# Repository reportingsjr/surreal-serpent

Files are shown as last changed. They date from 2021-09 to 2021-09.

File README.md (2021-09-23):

This light ring is intended to go on the intake of a fume extractor I am designing.

The assembly can be done by JLC excluding the Molex Picoblade connector on the back.

The input is a 12V PWM signal. At 100% duty cycle the current draw is approximately 450mA, divided evenly(ish) across ten strings of LEDs.

This project is only half organized, because I spent more time than I wanted on the design and assembly steps and don't feel like spending more energy organizing a hobby project. :)

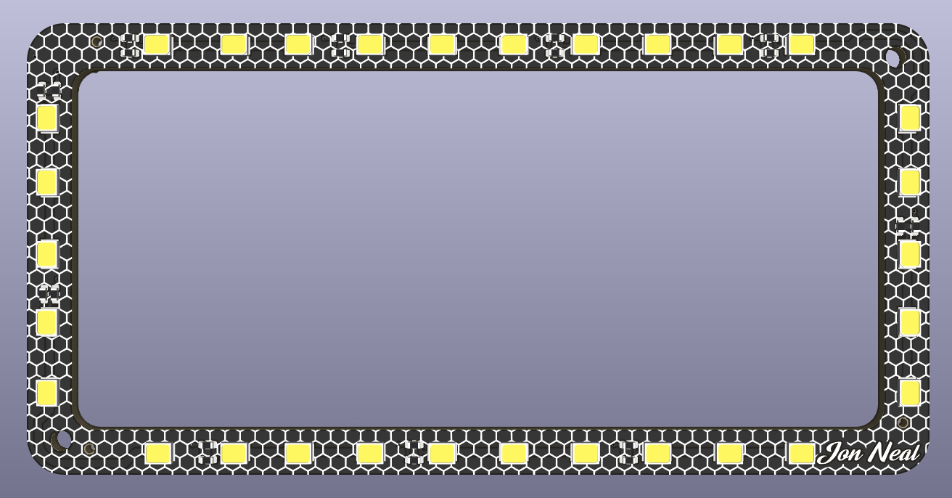
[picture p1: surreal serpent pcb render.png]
PCB Render


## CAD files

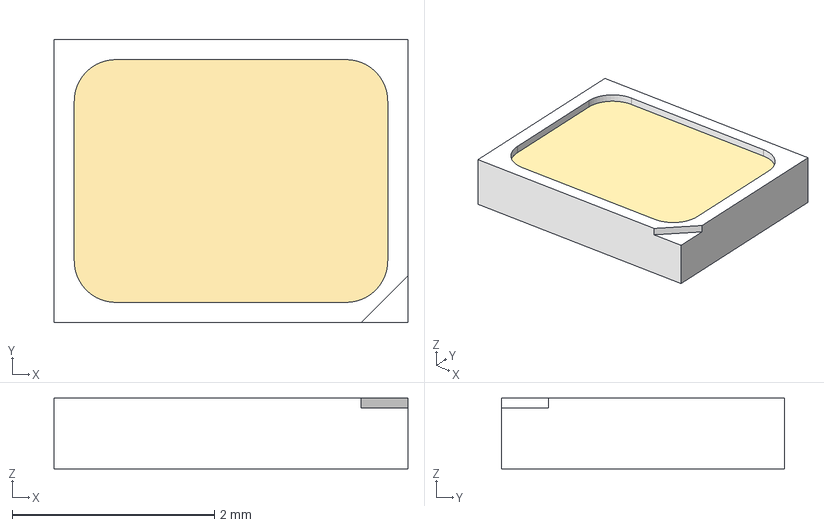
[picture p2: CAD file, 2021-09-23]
C210316.step
3.50 x 2.80 x 0.7 mm

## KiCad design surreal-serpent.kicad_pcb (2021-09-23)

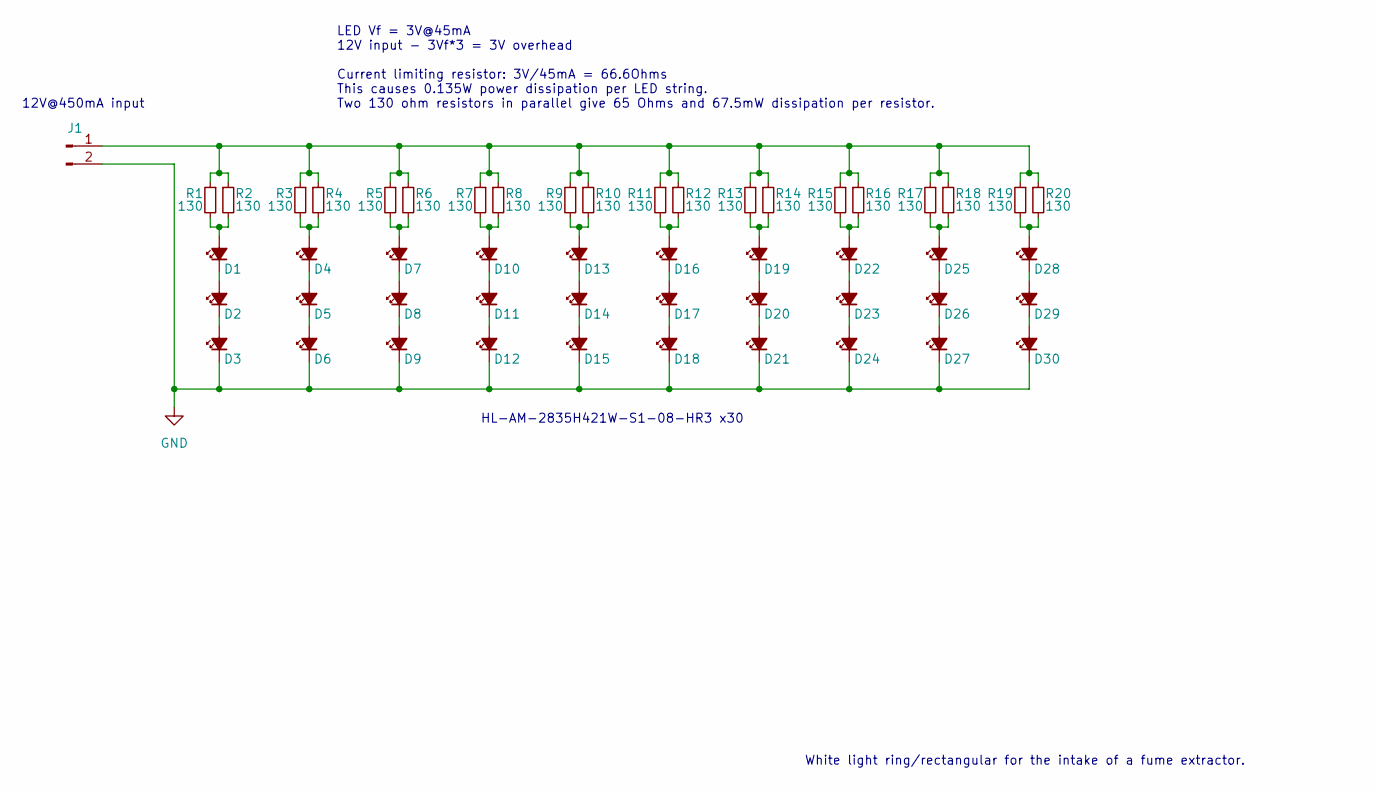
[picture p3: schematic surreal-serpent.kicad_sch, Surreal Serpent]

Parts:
D1, D2, D3, D4, D5, D6, D7, D8, D9, D10, D11, D12, D13, D14, D15, D16, D17, D18, D19, D20, D21, D22, D23, D24, D25, D26, D27, D28, D29, D30: HL-AM-2835H421W-S1-08-HR3; C210316; LCSC C210316
J1: Conn_01x02_Male; Molex_PicoBlade_53261-0271_1x02-1MP_P1.25mm_Horizontal; part number 0532610271
R1, R2, R3, R4, R5, R6, R7, R8, R9, R10, R11, R12, R13, R14, R15, R16, R17, R18, R19, R20: 130; R_0603_1608Metric; LCSC C22796

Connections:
GND: D3.1 (K), D6.1 (K), D9.1 (K), D12.1 (K), D15.1 (K), D18.1 (K), D21.1 (K), D24.1 (K), D27.1 (K), D30.1 (K), J1.2
unnamed: D1.1 (K), D2.2 (A)
unnamed: D1.2 (A), R1.2, R2.2
unnamed: D2.1 (K), D3.2 (A)
unnamed: D4.1 (K), D5.2 (A)
unnamed: D4.2 (A), R3.2, R4.2
unnamed: D5.1 (K), D6.2 (A)
unnamed: D7.1 (K), D8.2 (A)
unnamed: D7.2 (A), R5.2, R6.2
unnamed: D8.1 (K), D9.2 (A)
unnamed: D10.1 (K), D11.2 (A)
unnamed: D10.2 (A), R7.2, R8.2
unnamed: D11.1 (K), D12.2 (A)
unnamed: D13.1 (K), D14.2 (A)
unnamed: D13.2 (A), R9.2, R10.2
unnamed: D14.1 (K), D15.2 (A)
unnamed: D16.1 (K), D17.2 (A)
unnamed: D16.2 (A), R11.2, R12.2
unnamed: D17.1 (K), D18.2 (A)
unnamed: D19.1 (K), D20.2 (A)
unnamed: D19.2 (A), R13.2, R14.2
unnamed: D20.1 (K), D21.2 (A)
unnamed: D22.1 (K), D23.2 (A)
unnamed: D22.2 (A), R15.2, R16.2
unnamed: D23.1 (K), D24.2 (A)
unnamed: D25.1 (K), D26.2 (A)
unnamed: D25.2 (A), R17.2, R18.2
unnamed: D26.1 (K), D27.2 (A)
unnamed: D28.1 (K), D29.2 (A)
unnamed: D28.2 (A), R19.2, R20.2
unnamed: D29.1 (K), D30.2 (A)
unnamed: J1.1, R1.1, R2.1, R3.1, R4.1, R5.1, R6.1, R7.1, R8.1, R9.1, R10.1, R11.1, R12.1, R13.1, R14.1, R15.1, R16.1, R17.1, R18.1, R19.1, R20.1

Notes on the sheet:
12V@450mA input
LED Vf = 3V@45mA 12V input - 3Vf*3 = 3V overhead Current limiting resistor: 3V/45mA = 66.6Ohms This causes 0.135W power dissipation per LED string. Two 130 ohm resistors in parallel give 65 Ohms and 67.5mW dissipation per resistor.
HL-AM-2835H421W-S1-08-HR3 x30
White light ring/rectangular for the intake of a fume extractor.

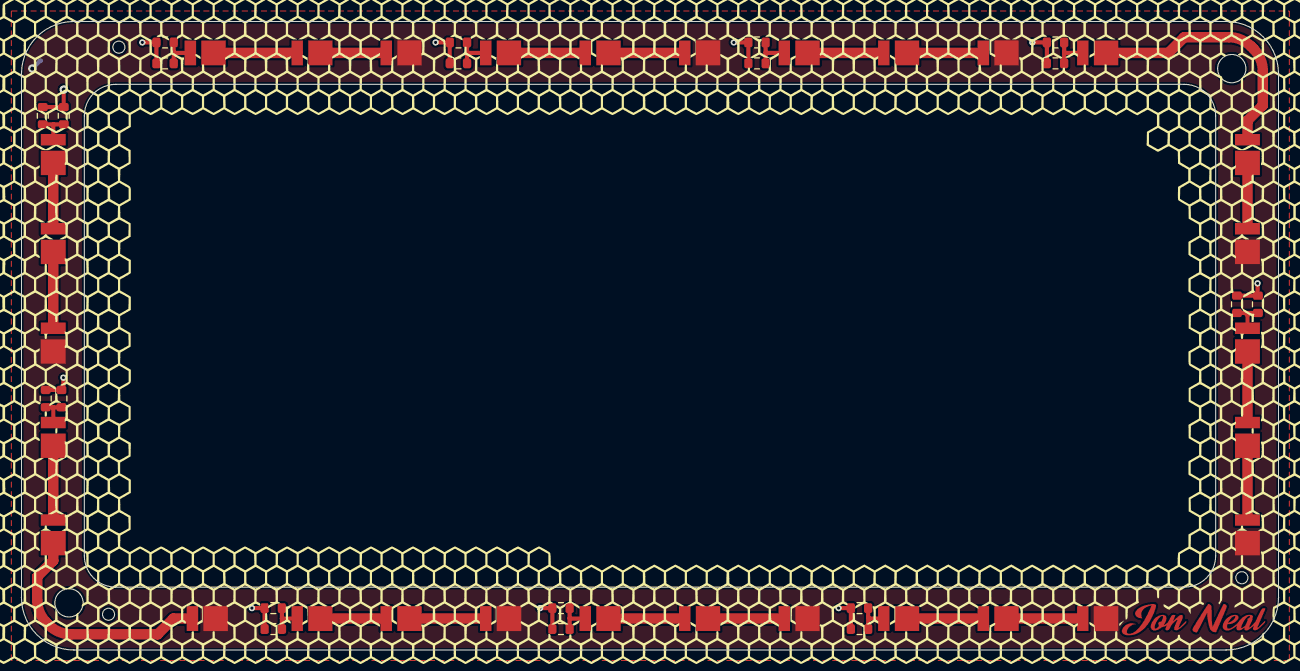
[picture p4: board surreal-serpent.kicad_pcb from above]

Board: 2 copper layers, 120.0 x 60.0 mm, 51 parts (1 on the bottom side), 32 nets.

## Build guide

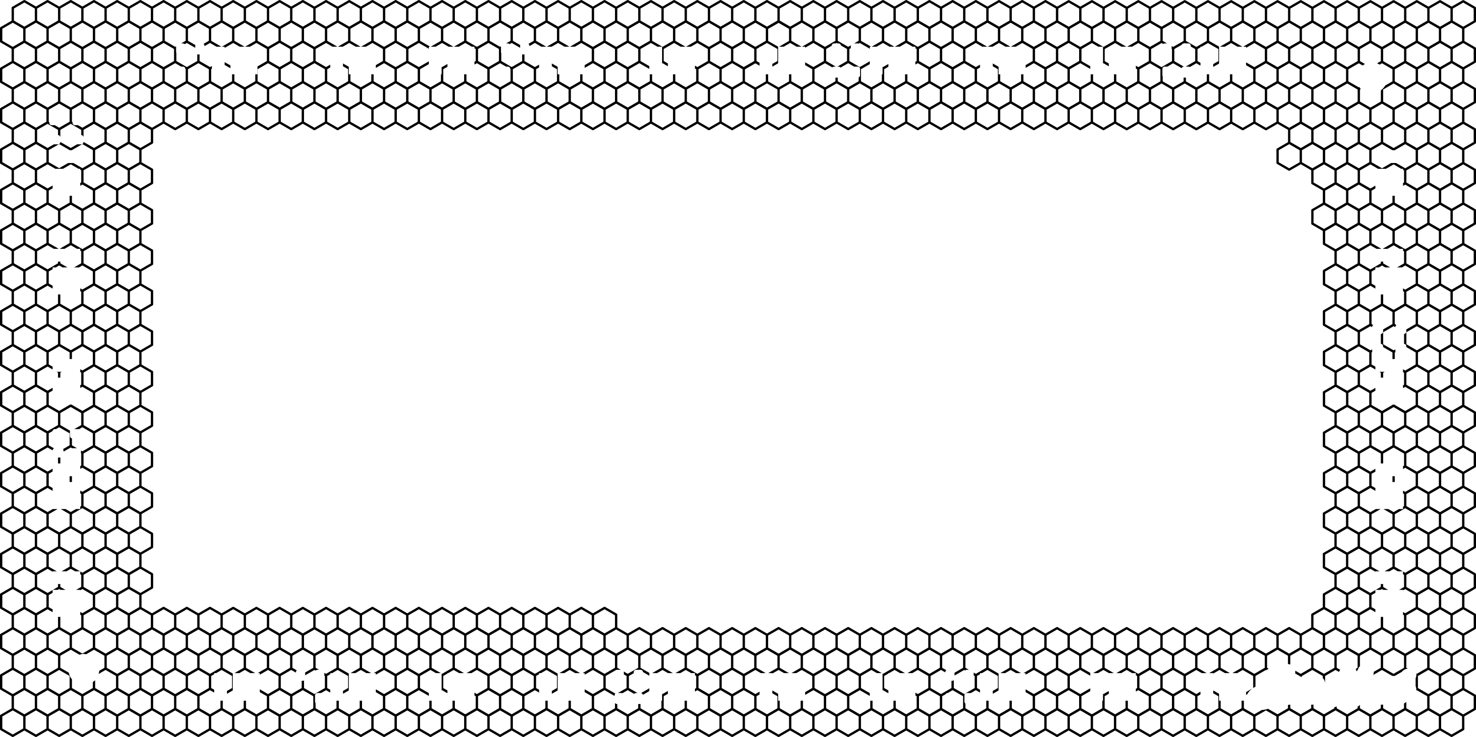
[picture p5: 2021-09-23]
silkscreen pattern/pattern_soldermask_large_name_cutout.png

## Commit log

2021-09-23 Initial release of design, untested, but ordered.
    [C210316.step, surreal-serpent.kicad_pcb, surreal-serpent.kicad_sch]
2021-09-23 Add board render image
2021-09-23 Update and rename README to README.md
    Also added PCB render.
